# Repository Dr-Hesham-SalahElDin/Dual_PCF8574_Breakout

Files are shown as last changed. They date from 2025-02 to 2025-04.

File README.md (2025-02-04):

# PCF8574 Dual I/O Expander Breakout Board

## Overview
This project is a **breakout board for two PCF8574 I/O expanders**, providing **16 digital I/O pins** (8 per expander) via **I²C communication**.  
The board allows users to configure the I²C addresses using **0Ω resistors**, making it flexible for different applications.

## Features
- **Dual PCF8574 ICs** providing **16 GPIOs**
- **I²C interface** for simple microcontroller integration
- **Configurable I²C addresses** using **0Ω resistors**
- **Onboard pull-up resistors** for I²C stability

## I²C Address Configuration
Each **PCF8574** has a **7-bit address**, where the lower 3 bits (`A2, A1, A0`) are user-configurable using **0Ω resistors**.

- **To set a bit to `0` (GND):** Solder the **0Ω resistor** between the address pin and **GND**.
- **To set a bit to `1` (VCC):** Solder the **0Ω resistor** between the address pin and **VCC**.

### Example Address Configurations
| A2 | A1 | A0 | I²C Address |
|----|----|----|---|
| 0  | 0  | 0  | `0x20` |
| 0  | 0  | 1  | `0x21` |
| 0  | 1  | 0  | `0x22` |
| 0  | 1  | 1  | `0x23` |
| 1  | 0  | 0  | `0x24` |
| 1  | 0  | 1  | `0x25` |
| 1  | 1  | 0  | `0x26` |
| 1  | 1  | 1  | `0x27` |

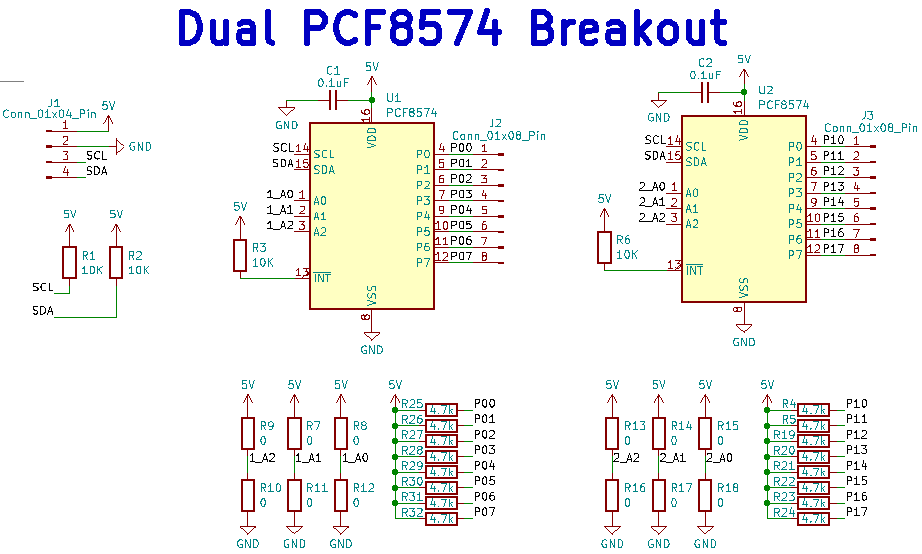
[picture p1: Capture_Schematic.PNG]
Schematic Diagram

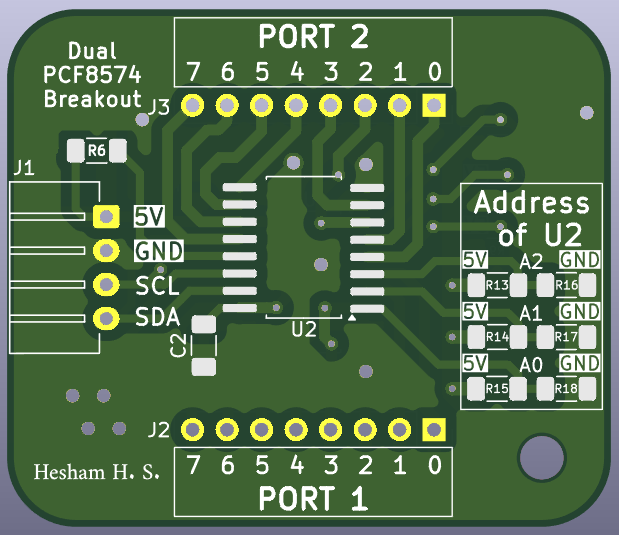
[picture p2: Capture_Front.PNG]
Front View

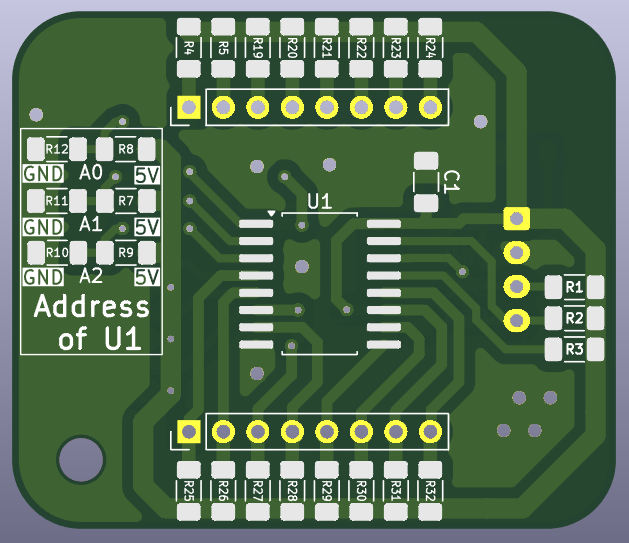
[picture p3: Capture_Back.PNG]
Back View


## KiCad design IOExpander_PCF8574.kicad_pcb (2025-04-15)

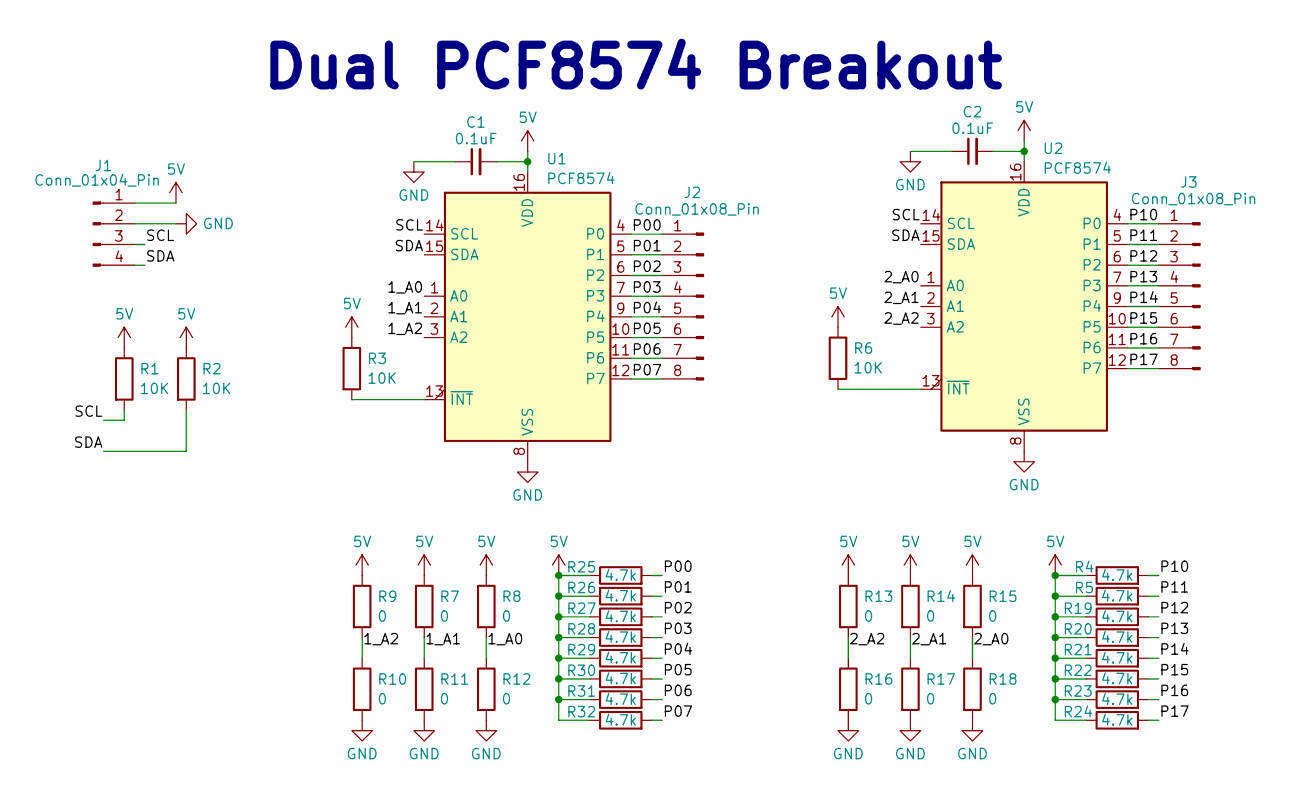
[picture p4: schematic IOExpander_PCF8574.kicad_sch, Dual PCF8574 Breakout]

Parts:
C1, C2: 0.1uF; C_1206_3216Metric_Pad1.33x1.80mm_HandSolder
J1: Conn_01x04_Pin; JST_XH_S4B-XH-A-1_1x04_P2.50mm_Horizontal
J2, J3: Conn_01x08_Pin; PinHeader_1x08_P2.54mm_Vertical
R1, R2, R3, R6: 10K; R_1206_3216Metric_Pad1.30x1.75mm_HandSolder
R4, R5, R19, R20, R21, R22, R23, R24, R25, R26, R27, R28, R29, R30, R31, R32: 4.7k; R_1206_3216Metric_Pad1.30x1.75mm_HandSolder
R7, R8, R9, R10, R11, R12, R13, R14, R15, R16, R17, R18: 0; R_1206_3216Metric_Pad1.30x1.75mm_HandSolder
U1, U2: PCF8574; SO-16_5.3x10.2mm_P1.27mm

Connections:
5V: C1.2, C2.2, J1.1, R1.1, R2.1, R3.1, R4.1, R5.1, R6.1, R7.1, R8.1, R9.1, R13.1, R14.1, R15.1, R19.1, R20.1, R21.1, R22.1, R23.1, R24.1, R25.1, R26.1, R27.1, R28.1, R29.1, R30.1, R31.1, R32.1, U1.16 (VDD), U2.16 (VDD)
/1_A0: R8.2, R12.1, U1.1 (A0)
/1_A1: R7.2, R11.1, U1.2 (A1)
/1_A2: R9.2, R10.1, U1.3 (A2)
/2_A0: R15.2, R18.1, U2.1 (A0)
/2_A1: R14.2, R17.1, U2.2 (A1)
/2_A2: R13.2, R16.1, U2.3 (A2)
/P00: J2.1, R25.2, U1.4 (P0)
/P01: J2.2, R26.2, U1.5 (P1)
/P02: J2.3, R27.2, U1.6 (P2)
/P03: J2.4, R28.2, U1.7 (P3)
/P04: J2.5, R29.2, U1.9 (P4)
/P05: J2.6, R30.2, U1.10 (P5)
/P06: J2.7, R31.2, U1.11 (P6)
/P07: J2.8, R32.2, U1.12 (P7)
/P10: J3.1, R4.2, U2.4 (P0)
/P11: J3.2, R5.2, U2.5 (P1)
/P12: J3.3, R19.2, U2.6 (P2)
/P13: J3.4, R20.2, U2.7 (P3)
/P14: J3.5, R21.2, U2.9 (P4)
/P15: J3.6, R22.2, U2.10 (P5)
/P16: J3.7, R23.2, U2.11 (P6)
/P17: J3.8, R24.2, U2.12 (P7)
/SCL: J1.3, R1.2, U1.14 (SCL), U2.14 (SCL)
/SDA: J1.4, R2.2, U1.15 (SDA), U2.15 (SDA)
GND: C1.1, C2.1, J1.2, R10.2, R11.2, R12.2, R16.2, R17.2, R18.2, U1.8 (VSS), U2.8 (VSS)
unnamed: R3.2, U1.13 (~INT)
unnamed: R6.2, U2.13 (~INT)

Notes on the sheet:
Dual PCF8574 Breakout

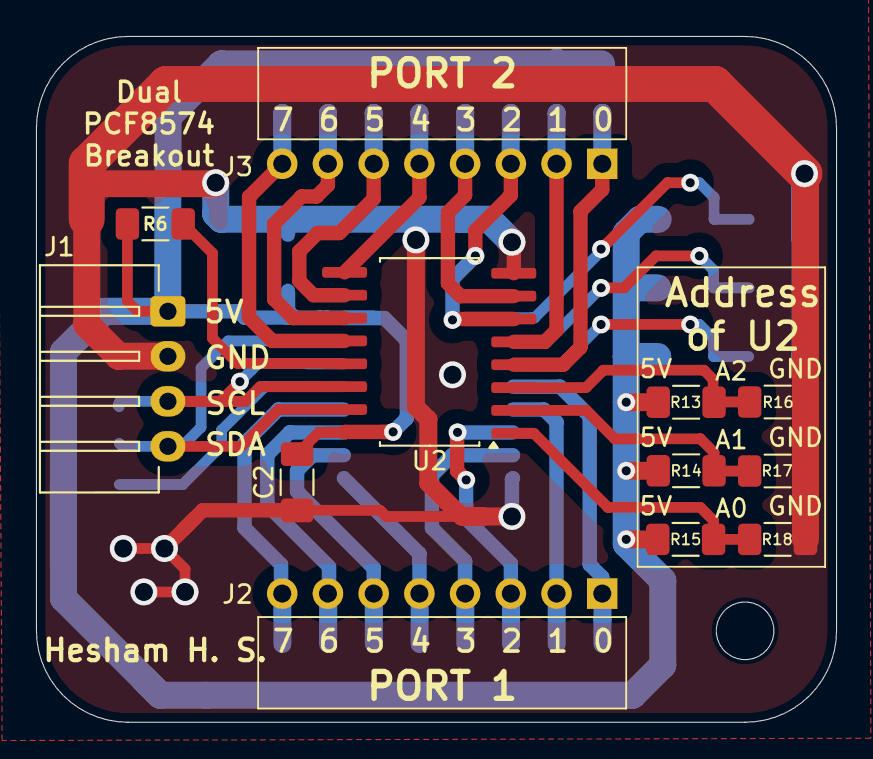
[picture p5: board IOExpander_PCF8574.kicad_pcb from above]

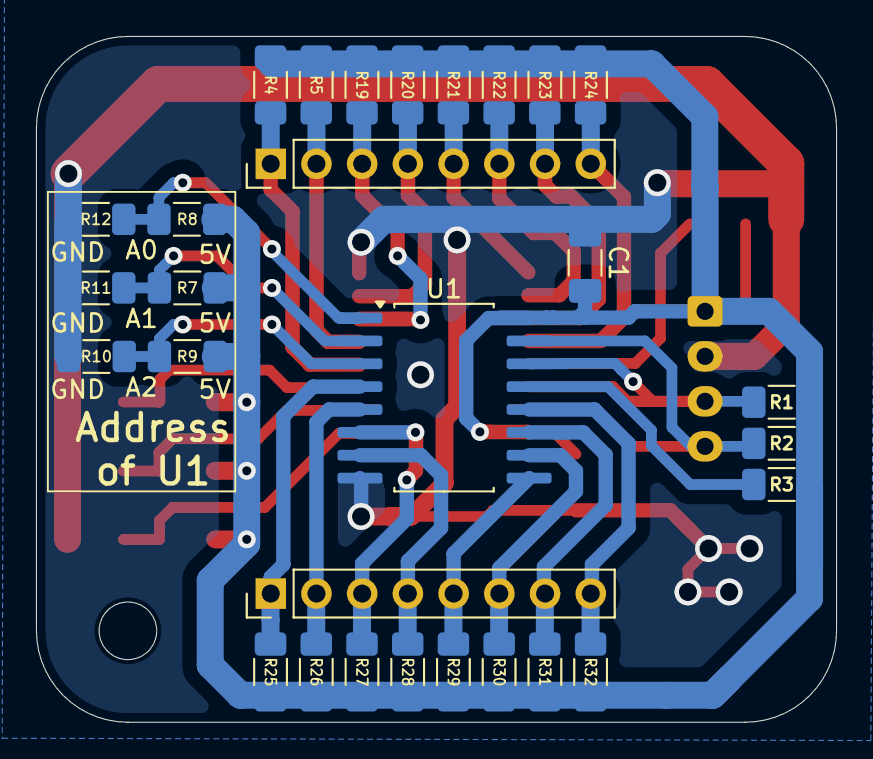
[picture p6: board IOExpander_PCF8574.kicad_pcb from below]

Board: 2 copper layers, 44.5 x 38.1 mm, 39 parts (29 on the bottom side), 28 nets.

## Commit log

2025-02-03 Updated the PCB Layout Silkscreen layer
    [IOExpander_PCF8574.kicad_pcb]
2025-02-04 Coupling Capacitors added
    [IOExpander_PCF8574-B_Cu.gbr, IOExpander_PCF8574-B_Mask.gbr, IOExpander_PCF8574-B_Silkscreen.gbr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]
2025-02-12 editing the footprint of PCF8574
    [IOExpander_PCF8574-B_Cu.gbr, IOExpander_PCF8574-B_Mask.gbr, IOExpander_PCF8574-B_Silkscreen.gbr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]
2025-04-15 Pull Up resistors are added for each channel
    [IOExpander_PCF8574-B_Cu.gbr, IOExpander_PCF8574-B_Mask.gbr, IOExpander_PCF8574-B_Silkscreen.gbr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]
